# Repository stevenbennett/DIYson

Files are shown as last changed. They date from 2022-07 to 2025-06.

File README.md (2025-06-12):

# The Open Task Light
Components for making the Open Task Light. Learn more on [Youtube](https://www.youtube.com/channel/UCvnxvXWYcOlmhRFvZ_ISP8g).

All designs are likely (probably guaranteed) to change. 3D models are updated regularly for education and experimentation but will almost certainly be updated, replaced, or removed in the future.

Find us on [Discord](https://discord.gg/B43ZVcBme4)

---
### NOTICE [MAY 2025]
There have been lots of hardware updates over the past few months (especially in the electronics department). I would suggest holding off on buying anything from the parts list until the project is wrapped and the BOM is updated. Let me know if you have any specific questions about any components in the meantime.

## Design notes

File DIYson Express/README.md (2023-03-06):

# DIYson Express
The DIYson express is the more approachable, completely customizable variant of the DIYson project. The Express is constructed from a simplified parts list which includes an out-of-the-box lighting and electronics solution. Check out the project video for a full overview: [https://www.youtube.com/watch?v=xv9rY6r6liI](https://www.youtube.com/watch?v=xv9rY6r6liI)

Sometimes the hardware costs can really add up, especially if you don't have the smaller M2 and M3 screws already on hand. For example; the M2 and M3 screw assortment normally costs $15.99USD, but the Express only requires 8 of them. That's about $2USD per screw. No good. To help with this, I put together a "Hardware Booster Kit" which includes the highest cost-per-part components and can help reduce costs by up to $50USD. Check it out here: [https://stevenbennett.gumroad.com/l/vseqv](https://stevenbennett.gumroad.com/l/vseqv) (note that you will still need a bunch of components found in the parts list, but all of them have a more reasonable cost-per-part and/or are logistically difficult for me to include in this kit).

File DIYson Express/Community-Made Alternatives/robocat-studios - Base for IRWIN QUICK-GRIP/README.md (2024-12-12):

# Alternative Base for IRWIN QUICK-GRIP Clamps

I got tired of fighting with the c-clamp base that is included in the project, so I designed this to be installed on an Irwin brand Quick-Grip clamp.

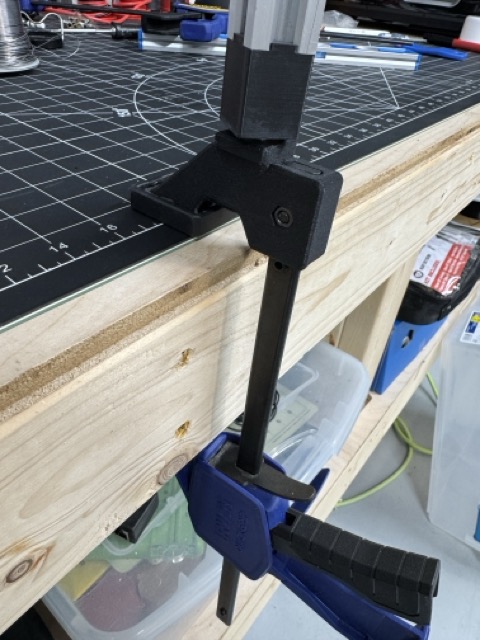
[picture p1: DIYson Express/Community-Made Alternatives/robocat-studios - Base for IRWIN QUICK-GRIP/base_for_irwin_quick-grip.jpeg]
Base for IRWIN QUICK-GRIP


## Parts to Buy

These clamps are fairly ubiquitous here in the US, available for sale at most major home improvement/hardware stores or on Amazon.

## How to Print

### Filament Type

I used PETG-CF, but you shouldn't need anything fancy. PLA or PETG will also work.

### Print Settings

Because of the cantilevered clamping force, you will need a fairly strong print. The model should already be oriented in the correct position. This has been working well for me:

- **Walls**: 5
- **Infill**: 50%
- **Infill Type**: Adaptive Cubic
- **Supports**: Optional\*

(\*) You might opt to enable supports if you find that the bridges are not as clean as you'd like. If you look closely at the picture, mine are drooping a bit, but it doesn't bother me.

## Assembly

It's super straight-forward, but for the sake of thoroughness:

1. Use a #2 Phillips screwdriver to remove the old clamp head.
2. Remove the rubber grip pad from the old clamp head and save it for re-use.
3. Install your fancy DIYson base clamp head.
4. Install the rubber grip pad.
5. Install the 40mm aluminum spacer that is used as the spindle for the lamp. I had to tap mine in with a mallet.
6. Enjoy your easily movable DIYson Express 🤙

Many thanks for Steven's work on this project. It's been great to follow on YouTube and I've been enjoying using the lamp.

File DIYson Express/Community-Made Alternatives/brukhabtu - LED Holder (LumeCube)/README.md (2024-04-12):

Holder for Lume Cube Bicolor Panel Mini LED Light

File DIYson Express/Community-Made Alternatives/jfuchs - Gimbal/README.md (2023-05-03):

# Gimbal end for the DIYson Express

This is a design that adds two more dimensions of control to the DIYson express.
It allows the same Ulanzi lamp recommended for the DIYson express to be mounted
on a gimbal.

## Parts to purchase

On top of the parts for the DIYson express, you will need only one 608ZZ
bearing. They are readily available on Amazon, AliExpress, eBay, and more.

## Printed parts

I've printed these parts in PLA with a 0.2mm layer height and a 0.4mm nozzle
with a max line width of 0.6mm. I have not tried other materials, but I suspect
PETG would work as well. The only challenging material constrait I know of is
that the outer ring has to bend enough to clip around the inner ring.

### Inner ring

The inner ring is a clip that goes around the lamp. It should be oriented so
that it clips around the sides of the lamp, leaving the buttons and the usb port
accessible. The inner ring has two recesses to press-fit in a 6mm⨉2mm ciruclar
magnet. It can be printed without support if printed on its side.

### Outer ring

The outer ring is a clip that goes around the inner ring. I printed it oriented
on its side, with support.

### Extrusion bracket

The extrusion bracket is a bracket that clips around the 2020 extrusion on one
end and receives a 608ZZ bearing on the other. If you print with the bearing
hold facing down, I was able to print it without support, but it did require
some bridging inside the hole (which will be hidden after assembly).

## Assembly

1. Press-fit the bearing around the post on the outer ring. I found a clamp or a
   vice will help with this.
2. Press-fit the bearing into the extrusion bracket. Again, a clamp may help —
   but you might need a spacer block inside the bracket to avoid crushing the
   tabs that fit around the extrusion.
3. Screw the extrusion bracket to the extrusion using the same Open Builds M5 x
   8mm low profile screws and M5 T-nuts as the rest of the DIYson Express.
4. Press-fit the two magnets into the inner ring. You may want to check the
   magnets against the lamp to make sure you get the polarity right. A clamp may
   help.
5. Clip the inner ring around the lamp.
6. Bend the outer ring just enough to fit it around the inner ring.

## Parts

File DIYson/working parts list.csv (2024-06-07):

Part Name | Quantity | Category | Link | European supplier | Note | Unit Cost (USD) | Total Cost (USD)
C-Clamp | 1 | Structure/Motion | https://amzn.to/3c4k5Et |  | Any small c-clamp will work | $15.10 | $15.10
GT2-2M Timing Belt (By the Foot) | 2 | Structure/Motion | https://openbuildspartstore.com/gt2-2m-timing-belt-by-the-foot/?ref=_2E7m4SXRIy8t | https://vslot-poland.com/timing-belt-GT2 |  | $2.49 | $4.98
Horizontal Rail (500mm) | 1 | Structure/Motion | https://openbuildspartstore.com/v-slot-20x20-linear-rail/?ref=_2E7m4SXRIy8t | https://vslot-poland.com/en_US/p/Aluminium-profile-2020-V-SLOT-Black-Anodized-250mm/38 |  | $3.29 | $3.29
Vertical Rail (500mm) | 1 | Structure/Motion | https://openbuildspartstore.com/v-slot-20x20-linear-rail/?ref=_2E7m4SXRIy8t | https://vslot-poland.com/en_US/p/Aluminium-profile-2020-V-SLOT-Black-Anodized-250mm/38 |  | $3.99 | $3.99
Xtreme Solid V Wheel Kit | 6 | Structure/Motion | https://openbuildspartstore.com/xtreme-solid-v-wheel-kit/?ref=_2E7m4SXRIy8t | https://vslot-poland.com/xtreme-solid-v-wheel-kit | Black Delrin or V-wheel kits can be substituted | $6.99 | $41.94
LED | 1 | Lighting | https://www.mouser.com/ProductDetail/Cree-LED/CXA1512-0000-000F0YJ430F?qs=G0uBbFPHMul3bnQg5K8bGQ%3D%3D | https://eu.mouser.com/ProductDetail/Cree-LED/CXA1512-0000-000F0YJ430F?qs=G0uBbFPHMul3bnQg5K8bGQ%3D%3D |  | $5.60 | $5.60
LED Housing | 1 | Lighting | https://www.mouser.com/ProductDetail/Ledil/F15256_HEKLA-SOCKET-D?qs=o2C7DKDMuStSi5P8paemqw%3D%3D | https://eu.mouser.com/ProductDetail/Ledil/F15256_HEKLA-SOCKET-D?qs=o2C7DKDMuStSi5P8paemqw%3D%3D |  | $1.37 | $1.37
LED Power Supply | 1 | Lighting | https://www.mouser.com/ProductDetail/919-RCD-24-0.70VREF |  |  | $18.94 | $18.94
Lens | 1 | Lighting | https://www.mouser.com/ProductDetail/928-CP16109 | https://eu.mouser.com/ProductDetail/928-CP16109 | Don't drop this, the tabs will break! | $4.98 | $4.98
6mm Idler Pulley (Pack of 10) | 1 | Hardware | https://amzn.to/3AthhKy | https://nl.aliexpress.com/item/1005004778728908.html?mp=1 |  | $11.99 | $11.99
Aluminum Spacers (40mm) (Pack of 10) | 1 | Hardware | https://openbuildspartstore.com/aluminum-spacers-10-pack/?ref=_2E7m4SXRIy8t | https://nl.aliexpress.com/item/10000404234974.html?mp=1 | Connects vertical rail to base | $7.89 | $7.89
Aluminum Spacers (6mm) (Pack of 10) | 1 | Hardware | https://openbuildspartstore.com/aluminum-spacers-10-pack/?ref=_2E7m4SXRIy8t | https://nl.aliexpress.com/item/10000404234974.html?mp=1 | Four needed for mounting wheels | $3.39 | $3.39
Assorted metric screws and nuts | 1 | Hardware | https://amzn.to/3camT2N | https://nl.aliexpress.com/item/33033655207.html?mp=1 | Used to secure belt clips and pulleys (don't get this unless you need the m2 and m3 screws, it's one of the most expensive items on the list) | $32.98 | $32.98
Black-Oxide Alloy Steel Hex Drive Flat Head Screw | 1 | Hardware | https://www.mcmaster.com/91294A002/ |  | Used to secure drag chain and strain relief clip | $8.75 | $8.75
Black-Oxide 18-8 Stainless Steel Pan Head Phillips Screws | 1 | Hardware | https://www.mcmaster.com/95836A277/ |  | Used to attach PCB to LED cover | $10.52 | $10.52
Eccentric Spacer (6mm) | 2 | Hardware | https://openbuildspartstore.com/eccentric-spacer/?ref=_2E7m4SXRIy8t |  |  | $1.99 | $3.98
Low Profile M5 Screws (15mm) (Pack of 10) | 1 | Hardware | https://openbuildspartstore.com/low-profile-screws-m5-10-pack/?ref=_2E7m4SXRIy8t | https://nl.aliexpress.com/item/1005003411992910.html?mp=1 | 4 needed to attach base and pulley assembly to vertical rail. One needed to tension the base | $1.19 | $1.19
Low Profile M5 Screws (25mm) (Pack of 10) | 1 | Hardware | https://openbuildspartstore.com/low-profile-screws-m5-10-pack/?ref=_2E7m4SXRIy8t | https://nl.aliexpress.com/item/1005003411992910.html?mp=1 | For mountng wheels to carriage and counterweight | $1.39 | $1.39
Low Profile Screw (Pack of 10) | 1 | Hardware | https://www.mcmaster.com/97710A129/ |  | Used to mount the LED assembly to the horizontal arm | $10.00 | $10.00
M3 Nyloc Nuts (Pack of 50) | 1 | Hardware | https://amzn.to/3Qxgn5a | https://nl.aliexpress.com/item/33030388407.html?mp=1 | Used in pulley assembly | $6.99 | $6.99
M5 Nyloc Nuts (Pack of 50) | 1 | Hardware | https://amzn.to/3T3DINM | https://nl.aliexpress.com/item/33030388407.html?mp=1 | Used in base | $6.49 | $6.49
Super Low Profile Nyloc Nut (pack of 4) | 2 | Hardware | https://www.getfpv.com/m5-black-aluminum-shallow-flange-lock-nut-set-of-4-cw.html | https://www.buildyourowndrone.co.uk/lumenier-m5-black-aluminum-low-profile-lock-nut-set-of-4-cw | For mountng wheels to carriage and counterweight | $4.99 | $9.98
Adafruit QT Py - SAMD21 | 1 | Electronics | https://www.adafruit.com/qtpy | https://eu.mouser.com/ProductDetail/Adafruit/4600?qs=hd1VzrDQEGi752M4exorSA%3D%3D |  | $7.50 | $7.50
MPM3610 5V Buck Converter Breakout | 1 | Electronics | https://www.adafruit.com/product/4739 |  |  | $5.95 | $5.95
Heatpipe | 1 | Cooling | https://www.mouser.com/ProductDetail/984-HPF5L300S13W236 | https://nl.mouser.com/ProductDetail/984-HPF5L300S13W236 |  | $14.02 | $14.02
Lighting PCB Pogo Pins | 3 | Electronics | https://mou.sr/3GX08v8 | https://www.digikey.nl/nl/products/detail/mill-max-manufacturing-corp/807-22-001-10-001101/5418772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 |  | $1.00 | $1.00

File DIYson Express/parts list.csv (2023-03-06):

Part Name | Quantity | Included in hardware booster kit? | Link | Note | Unit Cost | Total Cost
Open Builds 40mm Aluminum Spacer | 1 | Yes | https://openbuildspartstore.com/aluminum-spacers-10-pack/?ref=_2E7m4SXRIy8t | 10 pack, 1 used to connect to desk mount | $7.89 | $7.89
Open Builds Low Profile Screws M5x15mm | 1 | Yes | https://openbuildspartstore.com/low-profile-screws-m5-10-pack-/?ref=_2E7m4SXRIy8t | 10 pack, 2 needed for mounting base and pulley mount to vertical rail | $1.19 | $1.19
Low Profile Lock Nuts | 2 | Yes | https://www.readymaderc.com/products/details/rmrc-m5-cw-aluminum-low-profile-lock-nut-black-4pc | Optional (V Wheel kits come with standard silver lock nuts and you will have extra black ones from the pulley assembly) | $2.59 | $5.18
6mm Idler Pulley | 1 | Yes | https://amzn.to/3AthhKy | 10 pack | $11.99 | $11.99
M3 x 16mm Socket Head Screw | 1 | Yes | https://amzn.to/40agf0J | You only need one M3 screw for the whole lamp so if you don’t already have one your most affordable option is to get one from your local hardware store. | $11.99 | $11.99
Assorted M2 Screws | 1 | Yes | https://amzn.to/3HFifqF | Six 6mm and two 4mm screws are all you need. Used to mount belt to the carriage (4mm M2), the belt to the counterweight (6mm M2), and the lid to the counterweight (6mm M2) | $15.99 | $15.99
M3 Nylon Lock Nuts | 1 | Yes | https://amzn.to/3wFtVU4 | Pack of 50, need one for the pulley mounted at the top of the vertical rail | $7.49 | $7.49
C-Clamp | 1 | No | https://amzn.to/3c4k5Et | Any small c-clamp will work | $12.98 | $12.98
Open Builds Low Profile Screws M5 x 8mm | 1 | No | https://openbuildspartstore.com/low-profile-screws-m5-10-pack-/?ref=_2E7m4SXRIy8t | 10 pack, 5 needed for mounting the LED holder and the end cap to the horizontal rail | $0.99 | $0.99
Open Builds 500mm Linear Rail | 2 | No | https://openbuildspartstore.com/v-slot-20x20-linear-rail/?ref=_2E7m4SXRIy8t |  | $5.49 | $10.98
Open Builds 6mm Aluminum Spacer | 1 | No | https://openbuildspartstore.com/aluminum-spacers-10-pack/?ref=_2E7m4SXRIy8t | 10 pack, 4 used in mounting wheels to carriage | $3.39 | $3.39
Open Builds Xtreme Solid V Wheel Kit | 6 | No | https://openbuildspartstore.com/xtreme-solid-v-wheel-kit/?ref=_2E7m4SXRIy8t |  | $6.99 | $41.94
Open Builds Low Profile Screws M5 x 25mm | 1 | No | https://openbuildspartstore.com/low-profile-screws-m5-10-pack-/?ref=_2E7m4SXRIy8t | 10 pack, 6 needed for mounting wheels to carriage | $1.39 | $1.39
Open Builds 6mm Eccentric Spacer | 2 | No | https://openbuildspartstore.com/eccentric-spacer/?ref=_2E7m4SXRIy8t |  | $1.99 | $3.98
Open Builds Spring Loaded Tee Nuts | 4 | No | https://openbuildspartstore.com/spring-loaded-tee-nuts/?ref=_2E7m4SXRIy8t | Used to attach LED holder to horizontal rail | $1.29 | $5.16
GT2-2M Timing Belt | 2 | No | https://openbuildspartstore.com/gt2-2m-timing-belt-by-the-foot/?ref=_2E7m4SXRIy8t | Sold by the foot, cut down to 16.5 inches | $2.49 | $4.98
Lead Shot Balls | 1 | No | https://amzn.to/3kHrHAE | Please wear gloves while handling and wash your hands afterwards | $24.99 | $24.99
Open Builds Linear Rail End Cap | 1 | No | https://openbuildspartstore.com/end-cap/?ref=_2E7m4SXRIy8t | Optional (can be 3D printed) | $1.99 | $1.99
ULANZI L2 Bi-Color Light | 1 | No | https://amzn.to/3XTvSIA | Get two if you want 100% uptime | $36.99 | $36.99
10x5x2 Neodymium Magnets | 1 | No | https://amzn.to/3wZxsfU | Pack of 100 | $7.99 | $7.99
Duramic Matte Black Filament | 1 | No | https://amzn.to/3HiAHnv | Use whatever you like but this is my personal favorite | $19.99 | $19.99
Right Angle USB C Adapter | 1 | No | https://amzn.to/3DqzcT7 | Optional (only needed to make charging base) | $10.95 | $10.95

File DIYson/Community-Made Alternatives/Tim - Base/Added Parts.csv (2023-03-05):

Part Name | Quantity | Category | Link | European supplier | Note | Unit Cost (USD) | Total Cost (USD)
2-Wire Slipring | 1 | Hardware | https://www.amazon.com/dp/B09VKY42R4/ref=sr_1_8?keywords=electrical+slip+ring&qid=1676837754&sr=8-8 | https://www.amazon.de/dp/B01CJJNL46?psc=1&ref=ppx_yo2ov_dt_b_product_details | Used in the Base | $11.13 | $11.13
6004-2RS Bearing (Pack of 2) | 1 | Hardware | https://www.amazon.com/dp/B08DN95C11?__mk_de_DE=%C3%85M%C3%85%C5%BD%C3%95%C3%91 | https://www.amazon.de/dp/B0971WTC8Y?psc=1&ref=ppx_yo2ov_dt_b_product_details | Used in the Base | $17.50 | $17.50

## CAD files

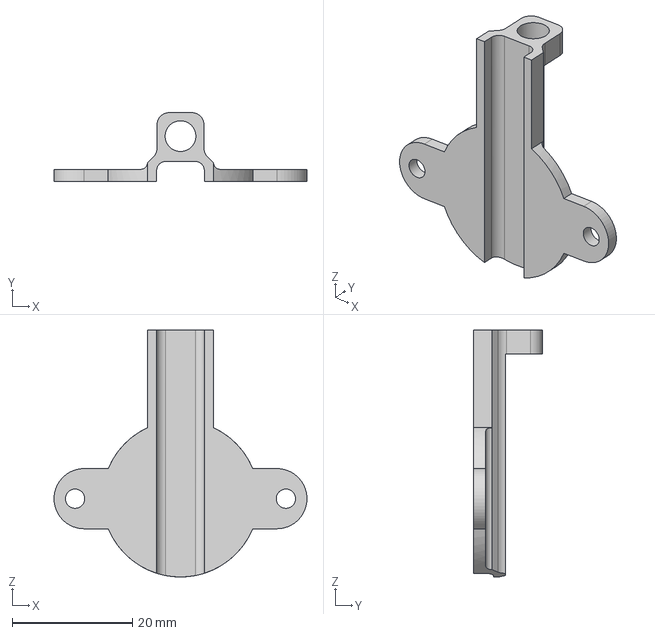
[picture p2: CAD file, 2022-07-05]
DIYson/Printed Parts/STEP/Lighting Assembly Mount.step
42.0 x 11.4 x 41.0 mm

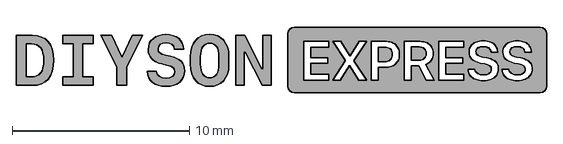
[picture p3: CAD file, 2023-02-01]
DIYson Express/Assets/express logo expanded.dxf
29.9 x 3.70 mm

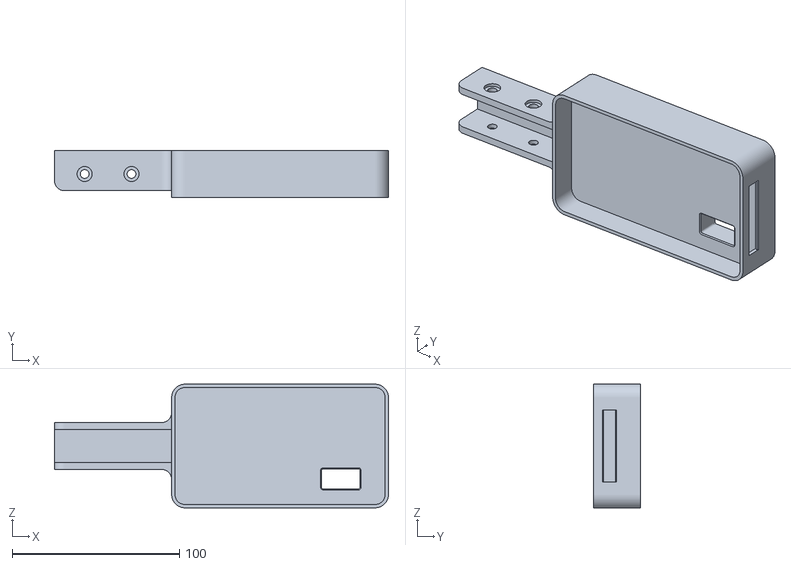
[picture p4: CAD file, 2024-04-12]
DIYson Express/Community-Made Alternatives/brukhabtu - LED Holder (LumeCube)/Lume Cube Bicolor Panel.stl
199.6 x 28.0 x 73.9

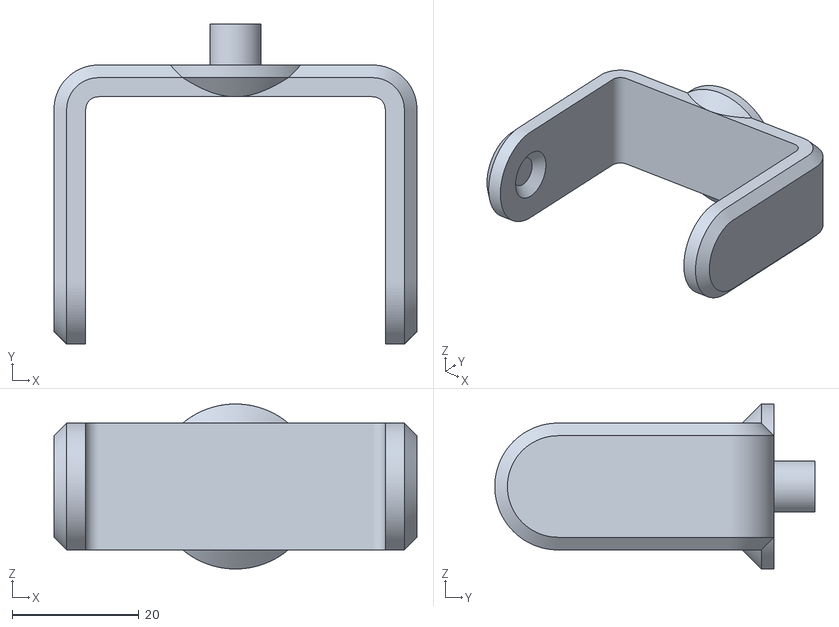
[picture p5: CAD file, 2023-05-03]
DIYson Express/Community-Made Alternatives/jfuchs - Gimbal/Outer ring.stl
57.2 x 50.5 x 26.0

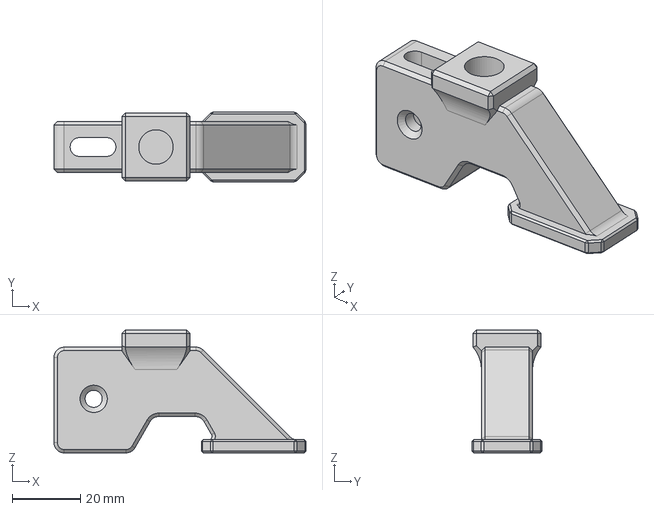
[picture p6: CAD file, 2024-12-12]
DIYson Express/Community-Made Alternatives/robocat-studios - Base for IRWIN QUICK-GRIP/Base for IRWIN QUICK-GRIP.step
73.9 x 20.5 x 36.0 mm

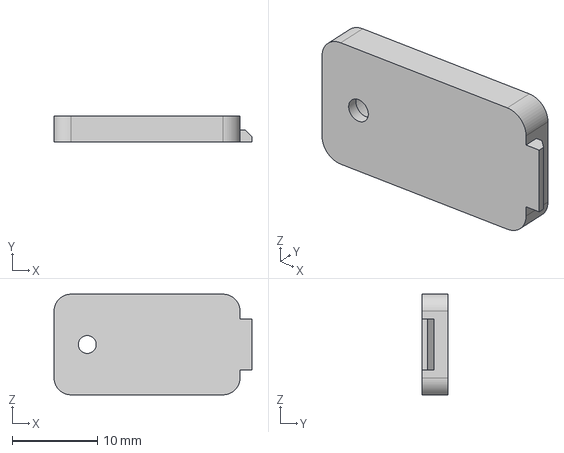
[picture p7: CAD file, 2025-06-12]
DIYson Express/Printed Parts/STEP/Coutnterweight Lid.step
23.2 x 3.00 x 11.8 mm

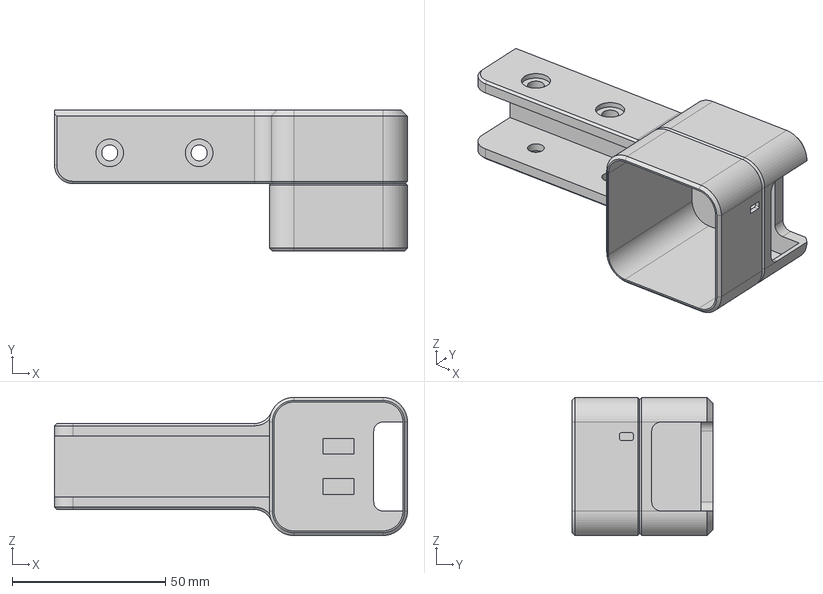
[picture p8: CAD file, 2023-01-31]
DIYson Express/Printed Parts/STEP/LED Holder Options/Ulanzi L2.step
115.0 x 46.0 x 45.0 mm

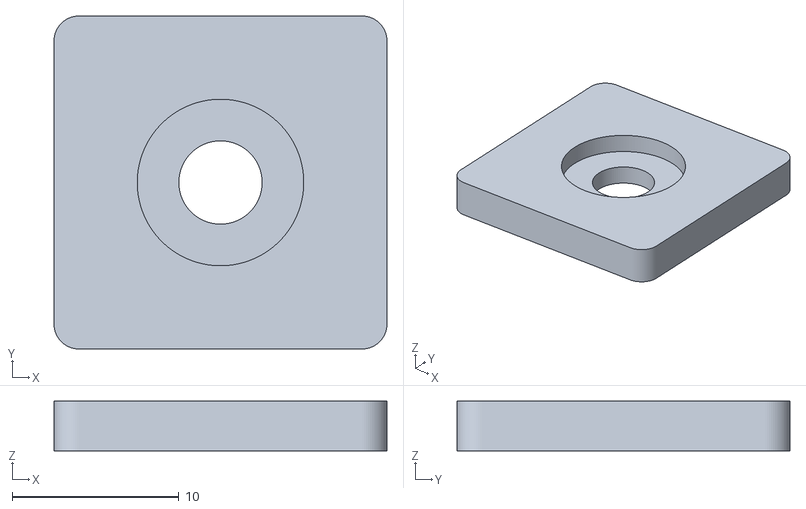
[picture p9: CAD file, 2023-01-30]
DIYson Express/Printed Parts/STL/End Cap (optional).stl
20.0 x 20.0 x 3.00

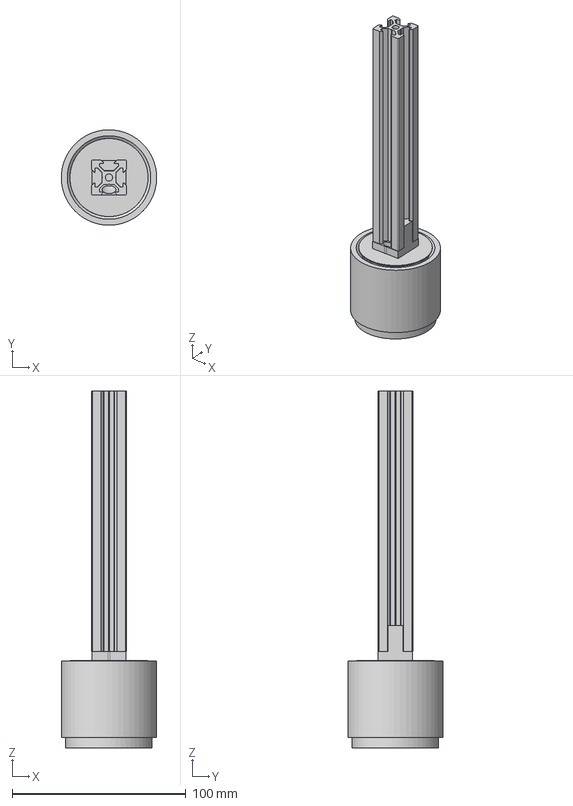
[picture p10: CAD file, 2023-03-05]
DIYson/Community-Made Alternatives/Tim - Base/Base.step
55.0 x 55.0 x 205.7 mm
Body_Kugel_einzeln (1) x 8
Body_Innenring (1)
Body_Aussenring (1)
20x20Rail
SlipRing
BoxUpper
BoxLower
Spacer
RailConnector

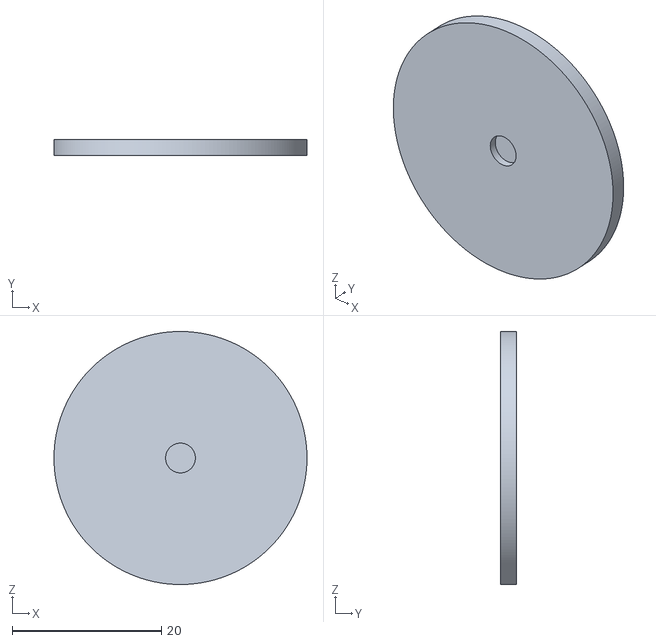
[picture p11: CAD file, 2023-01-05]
DIYson/Printed Parts/STL/Power Button.stl
33.9 x 2.10 x 33.9

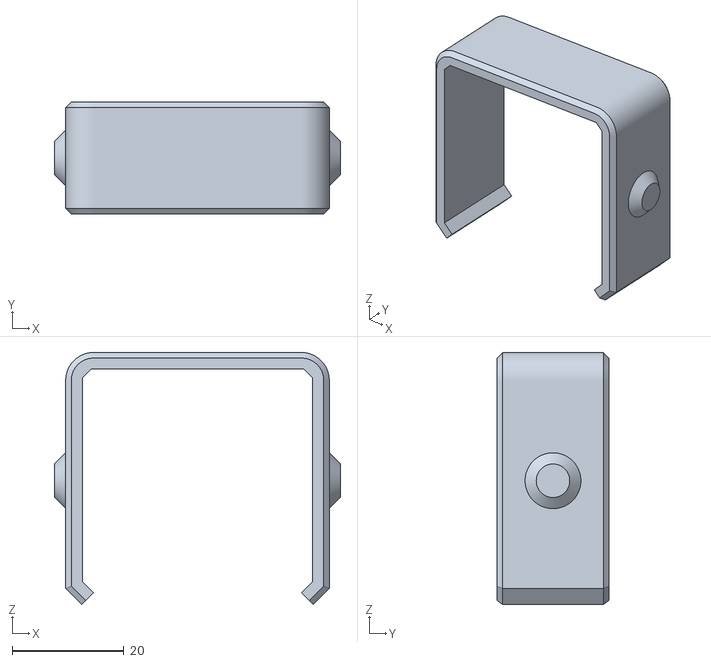
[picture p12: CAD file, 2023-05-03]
DIYson Express/Community-Made Alternatives/jfuchs - Gimbal/Inner ring.stl
51.2 x 20.0 x 45.1

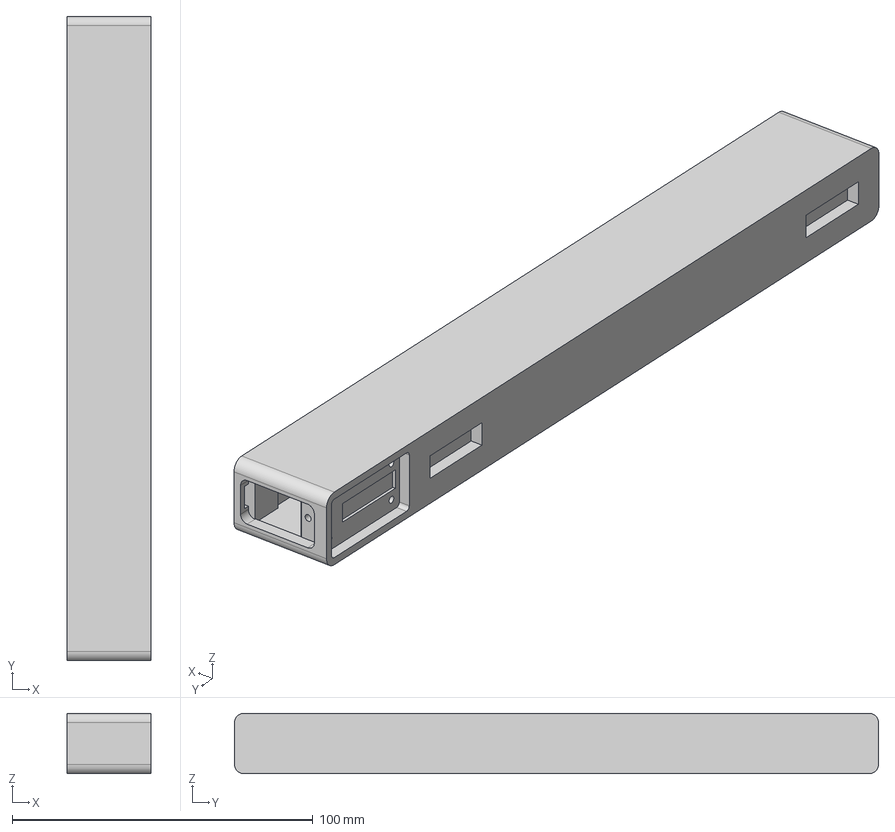
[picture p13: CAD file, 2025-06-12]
DIYson Express/Printed Parts/STEP/Coutnterweight Enclosure.step
28.0 x 214.0 x 20.0 mm

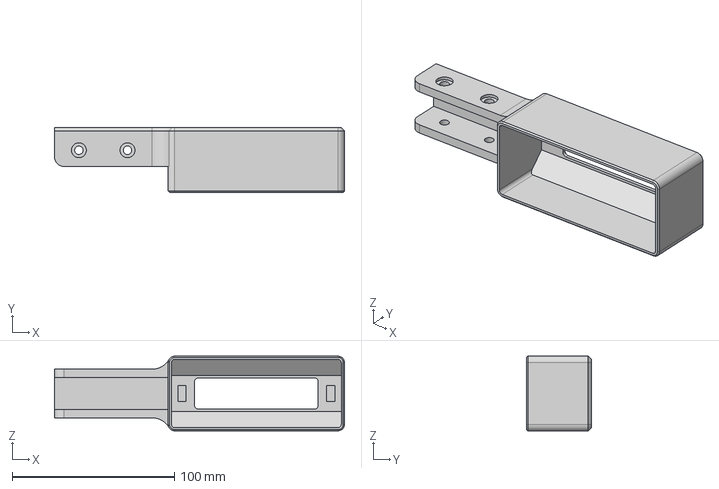
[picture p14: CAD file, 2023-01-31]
DIYson Express/Printed Parts/STEP/LED Holder Options/Ulanzi Wand.step
178.5 x 40.0 x 46.0 mm

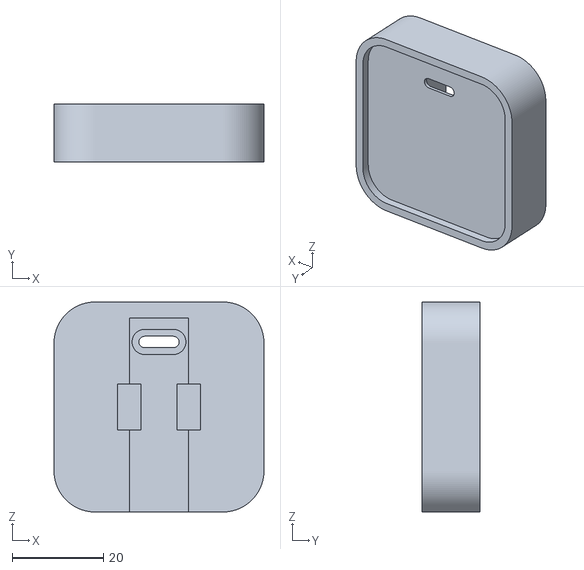
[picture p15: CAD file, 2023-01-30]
DIYson Express/Printed Parts/STL/Charging Base (optional).stl
46.0 x 12.8 x 46.0

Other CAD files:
DIYson Express/Community-Made Alternatives/brukhabtu - LED Holder (LumeCube)/LEDHolderLumeCube.step
DIYson/Printed Parts/STL/Increase Brightness Button.stl
DIYson Express/Community-Made Alternatives/jfuchs - Gimbal/Extrusion bracket.stl
DIYson Express/Community-Made Alternatives/robocat-studios - Base for IRWIN QUICK-GRIP/Base for IRWIN QUICK-GRIP.3mf
DIYson Express/Printed Parts/F3D/Base.f3d
DIYson Express/Printed Parts/F3D/Desk Mount.f3d
DIYson Express/Printed Parts/F3D/LED Holder Starter Template.f3z
DIYson Express/Printed Parts/STEP/Base.step
DIYson Express/Printed Parts/STEP/Carriage Belt Clip.step
DIYson Express/Printed Parts/STEP/Carriage.step
DIYson Express/Printed Parts/STEP/Chargine Base.step
DIYson Express/Printed Parts/STEP/Desk Mount.step
DIYson Express/Printed Parts/STEP/End Cap.step
DIYson Express/Printed Parts/STEP/Flex Tab.step
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

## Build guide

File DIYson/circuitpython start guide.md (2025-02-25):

## How to run Circuit Python on the QT Py ESP32-S2

1. Follow steps here to install CircuitPython: https://learn.adafruit.com/adafruit-qt-py-esp32-s2/circuitpython
2. Download the Adafruit libraries bundle version *9.x* from: https://circuitpython.org/libraries
3. Copy the following libraries to the `lib` folder:
- adafruit_debouncer.mpy
- adafruit_ticks.mpy
4. Copy the contents of [Code.py](DIYson/Code.py) or move the whole file onto the board, replacing the existing file.
5. Use your favorite editor to edit Code.py. Mu works well as-is. I personally use Visual Studio Code with the [CircuitPython v2](https://marketplace.visualstudio.com/items?itemName=wmerkens.vscode-circuitpython-v2) extensions for serial output.
<br>

**More resources**

[About Circuit Python](https://learn.adafruit.com/adafruit-qt-py/circuitpython)  
[More about the Adafruit QT Py ESP32-S2](https://learn.adafruit.com/adafruit-qt-py-esp32-s2/overview)

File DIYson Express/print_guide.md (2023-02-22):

# Part Printing Guide

###### General note: All parts can be printed using a layer height of .2mm and a .4mm nozzle unless noted otherwise below. Also these are just the settings I use so feel free to experiment and let us know if you come across a better method.

**Base:**  
Orientation: As installed (large hole side on build plate)  
Supports: On build plate  
Settings: 6 perimeters and 40% infill  
Notes: This part really does need to be strong, I have snapped a couple after I forget to bump up the number of perimeters 

**Carriage Belt Clip:**  
Orientation: Smooth side down  
Supports: On build plate  
Settings: I like to use .1mm layer height and Prusa Slicer's adaptive layer height feature  

**Carriage:**  
Orientation: Belt clip slot facing up  
Supports: On build plate  
Settings: 6 perimeters and 40% infill  

**Charging Base (optional):**  
Orientation: USB cable cavity on build plate  
Supports: On build plate  
Settings: Default  

**Counterweight Belt Clip:**  
Orientation: Small screw holes on build plate  
Supports: On build plate (or painted on to only support the countersink holes)  
Settings: Default  

**Counterweight Flex Tab:**  
Orientation: Vertical  
Supports: None  
Settings: Default  

**Counterweight Enclosure:**  
Orientation: Belt clip slot facing up (might have to sping 45 degrees to fit your print surface)  
Supports: None  
Settings: At least 4 perimeters  

**Counterweight Lid:**  
Orientation: Small screw holes on build plate  
Supports: None  
Settings: Default  

**Desk Mount:**  
Orientation: As installed (vertically with flat face on build plate)  
Supports: None  
Settings: 6 perimeters and 40% infill  

**End Cap (optional):**  
Orientation: Small screw hole on build plate  
Supports: None  
Settings: Default  

**Pulley Mount:**  
Orientation: As installed (linear rail inserts on build plate)  
Supports: On build plate  
Settings: Default  

**LED Holder Options:**  
Settings vary based on design, but the DIYson Express logo prints best with a .25mm nozzle. I print the Ulanzi L2 holder upside down (with the logo side on the build plate) and uses supports on the build plate to support the opening which reveal the buttons.

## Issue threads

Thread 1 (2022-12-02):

LED Housing alternatives?

jay-jey, 2022-12-02:
Hello, it seems that the housing of the LED is not longer availible, do you know any other housing that is working with the Lens and LED? There are so many different options, it is one of the smallest part but I think very important. Hope you cloud help me out with this.
BTW, very cool project.

FP15948_HEKLA-H

https://www.mouser.com/ProductDetail/Ledil/FP15948_HEKLA-H?qs=0lQeLiL1qybeRTKyjbFVcA%3D%3D

stevenbennett, 2022-12-02:
@jay-jey Hold tight for a bit because I've recently changed the LED and corresponding LED housing (due to issues like this where components abruptly become unavailable). Once I have the new LED tested I will update the BOM and this issue :)

stevenbennett, 2023-01-05:
@jay-jey Just updated the parts list with the new LED housing, and it's in stock woo!

stevenbennett, 2023-01-05:
It's this one btw: https://www.mouser.com/ProductDetail/Ledil/F15256_HEKLA-SOCKET-D?qs=o2C7DKDMuStSi5P8paemqw%3D%3D

Closed 2023-01-05.

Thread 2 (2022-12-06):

Belts width

jay-jey, 2022-12-06:
Hello,
I know the project is in early stage and not finsished at a all, but I allready printed some things out to tinker around a little bit. And I noticed that the openbuild belts are 5mm width. In 3D printing the belts are normaly 6mm. I think this could lead to some trouble, because I thing many people will have problem with this.

stevenbennett, 2022-12-12:
Fair point, it would be ideal to use a 6mm belt since that's what 3D printing enthusiasts will have on hand. Unfortunately the 6mm belt is to wide to fit within the aluminum rail channels (technically it does fit since the channel is just over 6mm wide, but the belt will tend to rub).

Closed 2022-12-12.

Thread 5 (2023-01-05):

LED Flicker

zamu-flowerpot, 2023-01-05:
Just watched your [latest video on YT (as of 2023/01/05)](https://www.youtube.com/watch?v=Emohi3FtTuM) and noticed that you are trying to power through a technical problem instead of using a technical solution!

LED Flicker is caused by having the PWM being out of sync with the camera's shutter speed. Instead of me trying to regurgitate how to fix this, check out RED digital camera's guide on flicker-free video [tutorial](https://www.red.com/red-101/flicker-free-video-tutorial).

So essentially, change either the camera shutter speed to something that is a multiple of 1000 (and whatever the stepping is) or change the LED's PWM and stepping to be a multiple of the camera shutter speed.

stevenbennett, 2023-01-05:
@zamu-flowerpot Thanks for the suggestion and guide, always good to have a walkthrough from an expert source.

This solution has been suggested a lot, and as far as I can tell the easiest way to test it is to change shutter speed from 29.97fps to 25fps (so that it is a divisor of 1000(hz)). Unfortunately this didn't work. Am I missing something? My next test will be to programmatically try every frequency from 1-1000 and see if there are any that eliminate banding.

DimaVIII, 2023-01-09:
@stevenbennett Here is your solution to the flickering problem. https://www.youtube.com/watch?v=DdToSNgPnO8&list=WL&index=64

You just need to go crazy high on the frequency, 150-300kHz seams to do the trick. You will need a [MOSFET](https://en.wikipedia.org/wiki/MOSFET) to drive it.
There is also the possibility that you need to change your microcontroller to a ESP32 (which is also quite small and has wifi + Bluetooth build in and costs around 2$) as your current one may not able to output such high frequency. This should solve also the power supply humming as this high frequencies can't be heard.

DimaVIII, 2023-01-10:
Here is a technical guide on how to dim analog LEDs.
https://quinled.info/2019/12/19/quinled-quad-hardware-guide-v1r6/

MarcoMobilio, 2023-02-17:
small comment on DimaVIII suggestion on using a mosfet to drive the led. If you are using a mosfet, can't you move the electronics back to the base? You need to carry to the lamp only ground and drain from the mosfet up to the led, like you are doing now with power. I know your custom PCB looks nice, but that would simplify the electronic distribution and give you more wiggle room.

B0rax, 2023-02-18:
> small comment on DimaVIII suggestion on using a mosfet to drive the led. If you are using a mosfet, can't you move the electronics back to the base? You need to carry to the lamp only ground and drain from the mosfet up to the led, like you are doing now with power. I know your custom PCB looks nice, but that would simplify the electronic distribution and give you more wiggle room.

you would still need wiring for the buttons...

Joseph0M, 2023-02-18:
You also would not be able to add hardware like ambient light and time of flight sensors required for some of the more advanced features.

MarcoMobilio, 2023-02-19:
Aaaaaand… I’m an idiot, you are both right, obviously 😅

stevenbennett, 2024-06-07:
Solved!

See:
203d19140b4c9bcb8ad206546123c115a8837234 and https://www.youtube.com/watch?v=mTmQzcG-7h4

Closed 2024-06-07.

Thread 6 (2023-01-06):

Lens link incorrect

mmrvelj, 2023-01-06:
Link for LED Lens is not correct, it direct to LED. Could you provide correct one?

stevenbennett, 2023-01-06:
@mmrvelj My bad, just fixed it (should have been https://www.mouser.com/ProductDetail/928-CP16109)

Closed 2023-01-06.

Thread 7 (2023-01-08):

500mm not 250mm in "working parts list.csv"

rcragger, 2023-01-08:
As title suggests, should the vertical and horizontal rails not be 500mm length as listed in [working parts list.csv](https://github.com/stevenbennett/DIYson/blob/main/working%20parts%20list.csv)

stevenbennett, 2023-01-11:
How did I miss this for so long? Thank you 🙏🏻

Closed 2023-01-11.

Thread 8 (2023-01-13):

Part list - Vertical rail

disq, 2023-01-13:
In the part list vertical rail (even though the length is now updated to 500mm) is showing as 20x40, which could be incorrect.

stevenbennett, 2023-01-15:
Thanks @disq

Closed 2023-01-15.

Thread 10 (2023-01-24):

linear power rail

fabianmuehlberger, 2023-01-24:
Hey Steven,

I watched your videos on youtube and the video about the drag chain made me think about other solutions for supplying power to the head of the lamp.

I know this has been discussed already but it might be a good solution for you

One way would be to coat the aluminum profile with PCB lacquer (eq. kontakt chemie plastik 70. ) and glue a flat aluminum conductor inside the slot. This would make it relatively safe to touch, assuming you only use 12V this isn't an issue. Then use copper brushes on the sliding part of your assembly to transfer the electricity (For testing you could use a solder wick, it comes in different sizes and is cheap, or look for replacement parts of the Carrera Toys). Technically you could use the aluminum profile as the earth, but having 1 conductor on each side where your wheels sit is an option.
You would need to build some tensioning spring to keep the brush engaged.

With the PCB lacquer being transparent and if you use an aluminum conductor, you won't have any visible cables, the overall part count is reduced and properly made I assume it can be very reliable over time with low maintenance besides replacing or adjusting the brushes.

I have some aluminum profiles in my workshop and can do some testing if you are interested.

Best
Fabian

fabianmuehlberger, 2023-01-24:
Just noticed the discussion feature. Therefore closed the issue

stevenbennett, 2023-01-30:
@fabianmuehlberger All good, thanks for sharing 👍🏻

Closed 2023-01-24.

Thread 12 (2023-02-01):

Filled Shopping Cart Links and Eccentric Spacer dimensions

momonunu, 2023-02-01:
This would be a link to the full openbuildstore cart for the diyson express (including the  end caps): https://saveyourcart.io/cart-url/qZya83ZUsDFTxaBH/db371481-3787-42a3-bb20-5ef49feb6bf3
I was not sure if the eccentric spacer is the 6mm variant or the 1/4“ version. In the cart above it is the 6mm version.

I am not sure however if the referral link gets saved in the saved cart.

tobias-holmes, 2023-02-01:
Thanks for sharing the saved cart. I noticed it was missing the 40 mm spacer to connect to the desk mount. Here is an updated cart: https://saveyourcart.io/cart-url/qZya83ZUsDFTxaBH/88853f4a-3ad2-4483-a033-878baa2b9b02.

I'm also assuming the 6 mm version of the eccentric spacer based on the step files. Please correct me if I'm wrong.

stevenbennett, 2023-02-01:
@momonunu @tobias-holmes Thanks for this! Yeah not sure if this will work with my referral link but this is just too convenient to pass up.

Best of both worlds; could this be set up using my site-wide referral link? https://openbuildspartstore.com/?ref=_2E7m4SXRIy8t

Not a huge deal if these things are incompatible, but I was hoping the referral commissions could help offset the project costs.

stevenbennett, 2023-02-01:
@momonunu @tobias-holmes And yes it's the 6mm eccentric spacer

momonunu, 2023-02-01:
Probably best to use the cart link first and then the sitewide referral in order to support you.

Closed 2023-02-08.

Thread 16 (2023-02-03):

Alternative light sources suggestion

monte-monte, 2023-02-03:
First of all, I'd like to say that I am very happy to find your project and that you keep everything so well documented and open. Your approach is really giving me an inspiration for my own work. I am working on my own lamp project and have sought cheap and readily available solution for a light module of some sort. So I bought a few types of LED spotlights on aliexpress for testing. I am driving them with custom circuitry so I'm not concerned with power supply's quality they came with.
I understand that this may be pretty big step away from your design and vision, but for someone who will try to repeat your project for themselves it could be easier to source mentioned chinese lamp modules.
The ones I've bought: https://www.aliexpress.com/item/1005004043668699.html, https://www.aliexpress.com/item/1005002848822524.html, https://www.aliexpress.com/item/1005004267786865.html
They are bulkier then your assembly, but I think some of them can be housed in some clever 3dprinted mount to better suit the overall aesthetics.

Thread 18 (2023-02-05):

Broken link to magnets in "parts list.csv"

BrilliantDeviation7, 2023-02-05:
[Link](https://amzn.to/3Rvrddv) to the magnets for the LED mount (DIYson Express) doesn't work. Typo or product page got removed?

stevenbennett, 2023-02-05:
@BrilliantDeviation7 Weird, looks like they were removed from Amazon. I just added a replacement. Thanks for letting me know

Closed 2023-02-05.

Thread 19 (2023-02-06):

[DIYson] Missing PCB Schematic/Electronic Designs

Joseph0M, 2023-02-06:
As seen in Video #7, It seems that the PCB design is absent from the files. I am sure the design will change from now, but it would be nice if the community could have a crack at the electronics. Also, the board outline + dimensions would be a nice addition.

stevenbennett, 2023-02-06:
@Joseph0M I would really like to put the PCB files up for folks to tinker with, but I need a little bit more time before I'm ready to share it/have people contribute to it.

Closed 2023-02-14.

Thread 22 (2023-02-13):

Consider securing the Base part with a through-bolt

dflemstr, 2023-02-13:
The Base part currently consists of a short bolt to attach it to an aluminum extrusion, and then the 40mm spacer to attach it to the Desk Mount.  This makes it quite brittle.

Gonna try to visualize using ASCII art, the drawing is not to scale :)

```
                                                      Bolt

                            ┌──────────────────────────┐ ┌───────────────────────────────┐
                            │                          │ │                               │
┌───────────────────────────┼───────────────┐   ┌───┐  │ │                               │
│                           │               │   │   ├──┼─┼─────┐                         │
│                           │               │   │   │  │ │     │                         │
│                           │               │   │   ├──┼─┼─────┘                         │
└───────────────────────────┼───────────────┘   └───┘  │ │                               │
                            │                          │ │                               │
40mm spacer                 └──────────────────────────┘ └───────────────────────────────┘
                                   3D printed base               Aluminum extrusion
```

An alternative is to use a long bolt that goes through both the 40mm spacer and through the Base 3D printed part and all the way into the aluminum extrusion.

```
Bolt                   ┌──────────────────────────┐   ┌─────────────────────────┐
                       │                          │   │                         │
┌───┐  ┌───────────────┼────────────────────────┐ │   │                         │
│   ├──┼───────────────┼────────────────────────┼─┼───┼────────┐                │
│   │  │               │                        │ │   │        │                │
│   ├──┼───────────────┼────────────────────────┼─┼───┼────────┘                │
└───┘  └───────────────┼────────────────────────┘ │   │                         │
                       │                          │   │                         │
                       └──────────────────────────┘   └─────────────────────────┘
        40mm spacer           3D printed base                 Aluminum extrusion
```

I've managed to do this with a 55mm or 60mm bolt quite easily with some minor tweaks to the 3D model using slicer hacks, so I think it should be quite straight-forward to update the original model as well.

stevenbennett, 2023-02-14:
@dflemstr Cool idea, this was one of my initial concepts actually (though I never mentioned it in any build logs). Since you have this implemented already maybe you can answer a question for me; does the screw ever unseat itself when turning the lamp counter-clockwise? Early on I worried that the friction on the screw head and a counter-clockwise turn might be enough to unscrew it, but perhaps that weight of the lamp prevents this. Any findings here?

Also thanks for the art, I like these :)

stevenbennett, 2023-02-14:
Oh sorry just reread and realized you may not have actually implemented this yourself. Maybe somebody can give it a try

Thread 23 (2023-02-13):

Consider supporting 6mm belts

dflemstr, 2023-02-13:
It seems to be way easier to find 6mm belts compared to 5mm belts, and it also seems to fit fine into all the aluminum extrusions I had laying around.

legopc, 2023-02-13:
Yeah I agree. I ordered 5mm belts just to be sure but I might also order some 6mm to compare. 6mm does fit, is easier to find locally so would be a good replacement for the partslist.

stevenbennett, 2023-02-14:
@dflemstr @legopc I'll keep it in mind. The nice thing about the 5mm belts is that as far as I know you can often find them where v-rollers and rails are sold. Though I appreciate that outside of that scenario that that 6mm belts are easier to find. Thanks for flagging that.

The 6mm belt will fit on paper, but there's a chance it will rub agains the aluminum rails. If either of you want to test out a 6mm belt let me know and I can send you the Fusion 360 files for the relevant parts and you can give it a go.

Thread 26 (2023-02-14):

pogo pin ideas

justme-1968, 2023-02-14:
just saw your latest video introducing the pogo pins and two things came to mind:

- maybe it would help to move the pogo pins nearer to the center of rotation instead of ‘far’ out on the side of the carriage. this would minimize the relative movement of the track and the pins to each other.

-  instead of the tracks being on the front and top sides they could be on the left and right sides so that they can be even closer to the center of the carriage. this would also minimize the distance between the pogo pins.

combining both ideas could allow mounting the pins somewhere inside the carriage which would make them even invisible. maybe the pins could be mounted to both sides of a small pcb that can be clipped into the carriage center between the upright and the arm. this would also eliminate the cable.

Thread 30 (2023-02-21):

Consider changing MCU to ESP32?

rorosaurus, 2023-02-21:
It would be really cool to consider the ESP32 for this project! I think [Seeed even makes a $5 drop-in replacement you could use!](https://www.seeedstudio.com/Seeed-XIAO-ESP32C3-p-5431.html)

Wifi/BT built-in opens a lot of doors! You could fine tune the color temp or brightness remotely from your phone, integrate the lamp with Google/Siri/Alexa, create schedules, auto-off timers, over-the-air updates, and Home Assistant automation!

As @DimaVIII pointed out, this would solve issue #5 with the LEDC peripheral, since we [have an 80MHz clock we can divide by however many bits of PWM duty resolution we want.](https://docs.espressif.com/projects/esp-idf/en/latest/esp32/api-reference/peripherals/ledc.html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)

The ESP32-CAM boards could be something to consider for an all-in-one solution for the color temperature matching feature. It might need a lot of calibration though!

Thanks for considering and for this awesome project (and entertaining videos)!

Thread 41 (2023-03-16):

Safer counterweight material

ekostjuk, 2023-03-16:
Why not use solid square tungsten/carbide bar (same or more densite than lead, 100% packed/efficient) + top-up with steel/copper balls for balance?

jfuchs, 2023-04-16:
I also had this concern. My current plan is to use fender washers like [these](https://www.amazon.com/Hillman-290012-Fender-Washer-100-Pack/dp/B000BD5GFU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) because they're easy to adjust and pack densely. I'll have to design a new enclosure for the counterweight, which will need to be thicker, but not as long.

jfuchs, 2023-04-17:
> I have kids running around the house, so anything lead is a no-no.

Yeah, similar concerns for me.

The nice thing about fender washers specifically is that their bore hole diameter is a small percentage of their outside diameter, so if you have them stacked, you're pretty close to packing the space as much as possible — at least if you're okay with the counterweight shape being dictated by the washer. I'm considering something like this:

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

But on the other hand, I recognize that this breaks with the rest of the design language. Suggestions welcome.

legopc, 2023-04-17:
Maybe we should take a page from monitor stands a take a look at springs as counterweight?

jfuchs, 2023-04-17:
> Maybe we should take a page from monitor stands a take a look at springs as counterweight?

As I understand it, a spring's force is going to vary with its displacement — but in this case i think you'd want it to be constant across different displacements. Maybe there are kinds of springs I don't know about though!

ekostjuk, 2023-04-18:
Long enough pre-loaded spring/elastic might be stable enough vs minimal friction across limited range of movement.
I'll keep looking for tungsten stock, as front plate is also done from polished bronzefill, which adds.

JeSuisAnanas, 2024-10-04:
How about filling the 3d printed part with sand or a sand epoxy mixture before printing the top layers?

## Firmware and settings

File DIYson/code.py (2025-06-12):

import microcontroller
import watchdog
import time, board, busio, math
import digitalio
import adafruit_veml7700
from analogio import AnalogIn, AnalogOut
from touchio import TouchIn
from adafruit_debouncer import Debouncer
from barbudor_tmp75 import TMP75

##################
# INITIALIZATION #
##################
DEFAULT_MAX_16_BIT_VALUE = 65535 # this is currently equal to 0% brightness. I need to make sure this variable name makes sense and is used consistently.
max_16_bit_value = DEFAULT_MAX_16_BIT_VALUE
DEFAULT_POWER_OUTPUT = 90 # out of 100. used for global max power ceiling
POWER_OUTPUT_LIMIT = DEFAULT_POWER_OUTPUT  # used to adjust max output based on temperature
DAC_BRIGHTNESS_FLOOR = 50000 # use this to ensure low brightness settings are visible/optimal. also allows you to manual adjust the brightness of the lowest brightness level.
DAC_OFF_VALUE = DEFAULT_MAX_16_BIT_VALUE
BRIGHTNESS_RANGE = DAC_OFF_VALUE - DAC_BRIGHTNESS_FLOOR

# INITIALIZE THE RX PIN WHICH WILL TURN OFF THE IC SWITCH AFTER BOOT
switch_control = digitalio.DigitalInOut(board.RX)
switch_control.direction = digitalio.Direction.OUTPUT
switch_control.value = False

# INITIALIZE THE DAC OUT TO CONTROL THE LED DRIVER
dac_out = AnalogOut(board.A1)
# SET THE LED DRIVER OUTPUT OFF
dac_out.value = DAC_OFF_VALUE

# could add a delay here to make sure DAC is initialized before handing over control

# TURN THE IC SWITCH OFF, TURNING CONTROL OVER TO THE QTPY
switch_control.value = True

microcontroller.watchdog.timeout = 2
microcontroller.watchdog.mode = watchdog.WatchDogMode.RESET


# INITIALIZE SENSORS
# LIGHT SENSOR (VEML7700)
i2c = busio.I2C(board.SCL, board.SDA)
light_sensor = adafruit_veml7700.VEML7700(i2c)
light_sensor.integration_time = 100  

# temperature sensor(TMP75)
temp_sensor = TMP75(i2c)

# BUTTONS
power_button_raw = TouchIn(board.A2)
increase_button_raw = TouchIn(board.TX)
decrease_button_raw = TouchIn(board.A3)
power_button = Debouncer(lambda: power_button_raw.value)
increase_button = Debouncer(lambda: increase_button_raw.value)
decrease_button = Debouncer(lambda: decrease_button_raw.value)


############
# SETTINGS #
############
# LAMP SETUP
_power = False  # False means lamp is off by default (don't change)
auto_brightness = False
temperature_scaling = True # Setting this false disables brightness scaling when temp sensor hits HIGH_TEMP. for safety the lamp will always turn off and stay off when it reaches MAX_TEMP
temperature_sample_rate = 5 #time in seconds to poll temperature sensor, not much benefit to reducing this (outside of testing)

# LED BRIGHTNESS CONFIG
# should probably update this so you can just declare one variable like `brightnesslevels = 4` and STEP, MIN_BRIGHTNESS, and MAX_BRIGHTNESS are calculated from that. This would allow you to easily go from 3 to 4 to 5 or even like 10 brightness levels without having to change a bunch of other variables. It might also break something even if you did all of that.
BRIGHTNESS_LEVELS = 4
STEP = 100 // BRIGHTNESS_LEVELS
MIN_BRIGHTNESS = STEP
MAX_BRIGHTNESS = STEP * (100 // STEP)
FADE_DURATION = 0.25
FADE_STEPS = 50
last_temp_check = 0

# AMBIENT LIGHT SENSOR CONFIG
LIGHT_SENSOR_MAX = 12000
LIGHT_SENSOR_MIN = 1

# TEMPERATURE SENSOR CONFIG
# these are conservative estimates based on PLA glass transition temperature of ~60c. can be bumped up a bit for PETG(75-80c) and bumped up quite a lot for polycarbonate 130c+ (check other component limits though...)
# internal temps can reach 56c if DEFAULT_POWER_OUTPUT is 100. haven't test at 90 or below.
HIGH_TEMP = 45
MAX_TEMP = 50

# CAPACITIVE TOUCH THRESHOLD, INCREASE IF TOO SENSITIVE
power_button_raw.threshold = 20000
increase_button_raw.threshold = 20000
decrease_button_raw.threshold = 20000


#############
# FUNCTIONS #
#############
# CLASSES
class Brightness:
    def __init__(self, percentage):
        self.flat_percentage = min(max(percentage, 0), 100)

    def as_driver_output(self):  # Converts from percentage to equivalent DAC output for the driver
        if self.flat_percentage == 0:
            return DAC_OFF_VALUE
        # Scale the brightness by the power output limit
        effective_percentage = (self.flat_percentage * POWER_OUTPUT_LIMIT) / 100
        normalized_brightness = effective_percentage / 100
        scaled_brightness = 1 - (normalized_brightness ** 2)
        dac_value = int(scaled_brightness * DAC_BRIGHTNESS_FLOOR)
        return dac_value

class AmbientBrightness:
    def __init__(self, sensor, min_value, max_value):
        self.sensor = sensor
        self.min_value = min_value
        self.max_value = max_value
        self.last_task_time = time.monotonic()

    def update(self): #limit frequency of value updates (hopefully allows lamp to wait for stable lighting conditions)
        if time.monotonic() - self.last_task_time >= 2:
            self.last_task_time = time.monotonic()
            return self.sensor.lux
        return None

    def get_brightness_lux(self):
        return self.sensor.lux


    def get_brightness_percentage(self): #converts the lux value to a scaled value then to a percentage to compare to user_brightness
        lux = self.sensor.lux
        shifted_lux = lux - self.min_value + 1  
        normalized_lux = shifted_lux / (self.max_value - self.min_value + 1)
        scaled_brightness = (math.log(normalized_lux * 9 + 1) / math.log(10)) * 100

        return min(max(scaled_brightness, 0), 100)


# SET INITIAL BRIGHTNESS
user_brightness = Brightness(STEP)
output_brightness = Brightness(0)
ambient_brightness = AmbientBrightness(light_sensor, LIGHT_SENSOR_MIN, LIGHT_SENSOR_MAX)


def get_temperature():
    # debugging
    # print(f"Temperature: {temp_sensor.temperature_in_C}°C")

    return temp_sensor.temperature_in_C

def set_output_brightness(target_brightness, duration=FADE_DURATION):
    global output_brightness
    step_duration = duration / FADE_STEPS

    # manually set some end points if start or end value is "off" for smoother tranistions
    start_value = DAC_OFF_VALUE if output_brightness.flat_percentage == 0 else output_brightness.as_driver_output()
    end_value = DAC_OFF_VALUE if target_brightness.flat_percentage == 0 else target_brightness.as_driver_output()

    for step in range(FADE_STEPS + 1):
        fraction = step / FADE_STEPS
        current_value = int(start_value + (end_value - start_value) * fraction)
        dac_out.value = current_value
        time.sleep(step_duration)

    output_brightness = target_brightness

    # debugging
    # print(f"Current brightness: {output_brightness.flat_percentage}% | DAC Output: {output_brightness.as_driver_output()}")
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

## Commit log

2022-05-21 Added printed parts
    [Base.step, Base.stl, Belt Clip.step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]
2022-07-05 Brightness control script (for Trinket M0)
    Added python script for LED brightness control
2022-07-05 Added new models for printed parts
    Added STL and STEP files for the lighting assembly mount
    [Lighting Assembly Mount.step, Lighting Assembly Mount.stl]
2022-07-10 Added (working) parts list
    [working parts list.xlsx]
2022-07-10 Swapped parts list excel sheet for csv
    [working parts list.csv, working parts list.xlsx]
2022-07-10 Added c-clamp to parts list
    [working parts list.csv]
2022-07-10 Updated parts list
    Sorted by category
    Fixed vertical rail link
    [working parts list.csv]
2022-08-10 LED Cover, carriage update, and 20x20 vertical rail
    Added a V1 cover design for the LED assembly
    Streamlined the carriage to remove excess material
    Reverted back to the 20x20mm vertical rail with an updated counterweight
    [Base.step, Base.stl, Carriage.step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]
2022-08-18 Updated links in parts list
    [working parts list.csv]
2022-09-27 Update working parts list.csv
    [working parts list.csv]
2022-10-18 Added cable drag chain
    - Updated carriage to allow mounting of drag chain
    - Modified belt clip for easier CNC routing of carriage
    - Added special "routed spacer" to replace on aluminum spacer on the carriage (necessary for cable routing between drag chains)
    [Belt Clip.step, Belt Clip.stl, Carriage.step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]
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2023-01-04 Update working parts list.csv
    Added some links to european/aliexpress supplier for the linked parts which are in stock at the moment. I tried to use as few different suppliers as possible.
    [working parts list.csv]
2023-01-05 Build log #7 changes
    Parts and code updates to reflect Build log #7 updates
    [Base.step, Base.stl, Brightness Button Socket.stl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]
2023-01-05 Create Drag Chain (16 links, print-in-place).stl
    Added print-in-place drag chain with 16 links
    [Drag Chain (16 links, print-in-place).stl]
2023-01-05 Update working parts list.csv
    Added:
    - Updated LED (see buildlog #7)
    - LED housing (for compatibility with new LED)
    - LED power supply (for compatibility with new LED)
    - QT PY SAMD21 (see buildlog #7)
    - MPM3610 5V Buck Converter (see buildlog #7)
    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
    [working parts list.csv]
2023-01-05 Update working parts list.csv
    Add quotation marks to notes
    [working parts list.csv]
2023-01-06 Update working parts list.csv
    Replaced EU source for super low profile m5 lock nuts (the ones listed weren't locking)
    [working parts list.csv]
2023-01-11 Update working parts list.csv
    Fixed linear rail length (was 250mm, should be 500)
    Added pogo pins
    [working parts list.csv]
2023-01-15 Update working parts list.csv
    Updated vertical rail from 20x40 to 20x20
    [working parts list.csv]
2023-01-30 Added DIYson Express Directory and project files
    I've added a variant of the DIYson called the DIYson Express. It's a more approachable alternative to the project that allows you to build a simplified DIYson without the ever-increasing skill and co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
    - All STLs have been added to the subdirectory
    - Added a Fusion 360 template to help with making your own LED holders
    - Added a full parts list specifically for the Express
    [Base.step, Base.stl, Belt Clip.step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]
2023-01-31 Added DIYson Express STEP Files
    [Base.step, Carriage Belt Clip.step, Carriage.step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]
2023-02-01 Create express logo expanded.dxf
    Added DIYson Express logo dxf file
    [express logo expanded.dxf]
2023-02-01 Update parts list.csv
    Changed screws used to fasten carriage belt clip from M2x6mm to M2x4mm
    [parts list.csv]
2023-02-02 Add 6mm to eccentric spacer
    [parts list.csv]
2023-02-05 Update parts list.csv
    Replaced discontinued magents
    [parts list.csv]
2023-02-05 Fixed magnet link
    [parts list.csv]
2023-02-06 Updated M5 lock nuts in parts list
    Updated with some shorter and less expensive M5 lock nuts for the carriage (also they are currently in stock which is nice)
    [parts list.csv]
2023-02-09 Create print_guide.md
    This is a first pass at a print guide. It's rough but hopefully gives folks a good starting point.
2023-02-10 Update LED Control.py
    Updated sleep duration in fadeBetween (was 10x too slow)
    Restored lost line initially setting pwm to 0 which allows the LED to fully power off while power = false (I had deleted accidentally)
2023-02-14 Updated counterweight design
    [Counterweight - Lid.step, Counterweight - Lid.stl, Counterweight Belt Clip.step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]
2023-02-14 Pulley mount tweak
    Optimized pulley mount a bit to reduce interference with the belt
    [Pulley Mount.step, Pulley Mount.stl]
2023-02-17 Create Base.f3d
    Added Fusion 360 file for base for @dflemstr and @legopc
    [Base.f3d]
2023-02-22 Update print_guide.md
    Correct titles to reflect printed items.
2023-02-22 Create Desk Mount.f3d
    [Desk Mount.f3d]
2023-03-04 Added dir + needed Parts
    [Added Parts.csv]
2023-03-04 Add removed Parts
    [Removed Parts.csv]
2023-03-05 Added new base files
    Base.f3d --> names are in german. Added to change tolerances (if needed)
    [Base.f3d, Base.step]
2023-03-06 Express hardware booster kit updates
    Added Express README with link to hardware booster kit
    Added column in DIYson Express parts list to indicate whether a part is included in the hardware booster kit
    [parts list.csv]
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2023-05-02 Add the gimbal alternative for the DIYson Express
    [Extrusion bracket.stl, Inner ring.stl, Outer ring.stl]
2023-09-02 Renamed community mods directory
    [Extrusion bracket.stl, Inner ring.stl, Outer ring.stl]
2023-10-19 Renamed community alternatives directory
    [Added Parts.csv, Base.f3d, Base.step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]
2023-11-11 Update working parts list.csv
    Added note about lens fragility
    [working parts list.csv]
2023-12-24 Update working parts list.csv
    Changed source for led control pogo pins from digikey to mouser (issue #46) thanks @hornej
    [working parts list.csv]
2024-01-25 Add LED Holder for LumeCube
    [LEDHolderLumeCube.step]
2024-04-07 Create circuitpython-start-guide.md
    A reminder for myself and others of how to get a new QT Py up and running with Circuitpython, what libraries are needed, and where to find things
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2024-04-12 Added STL and Readme
    [Lume Cube Bicolor Panel.stl]
2024-06-07 Added new LED driver to parts list
    [working parts list.csv]
2024-12-11 Add alternative base for IRWIN QUICK-GRIP clamps
    [Base for IRWIN QUICK-GRIP.3mf, Base for IRWIN QUICK-GRIP.step]
2025-02-25 Main board updates (code.py overhaul)
    Should have pushed this sooner. Changed a lot of stuff on the main board:
    - Changed microcontroller from the QT Py SAMD21 to the QT Py ESP32-S2
    - Added analog temperature sensor
    - Added ambient light sensor
    - Complete overhaul to LED Control.py (now code.py) to accommodate above components and clean up code
2025-02-28 Update code.py
    inverted output from as_driver_output method in Brightness class
    ensure driver output is 0 when lamp is off
    switched capacitive buttons touch detection from .fell to .rose to prevent false touches on startup
    [code.py]
2025-06-12 Code updates
    Too many changes to list, check out the code comments for more info. Mostly uploading for backup purposes.
    - switched to qt py esp32 s2
    - added brightness classes for ambient and LED output brightness
    - simplified main loop
    - support for i2c sensors (temperature and brightness)
    - added a bunch of comments (for future me and others)
    TODO:
    - started working on a watchdog function to prevent lock-ups which would require a physical reset. need to replace the current solution with something using microcontroller.reset
    [code.py]
2025-06-12 Counterweight lid improvements
    - New design requires only one screw
    - A bit wider to make it easier to fill
    - Better looking
    [Coutnterweight Enclosure.step, Coutnterweight Enclosure.stl, Coutnterweight Lid.step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]
